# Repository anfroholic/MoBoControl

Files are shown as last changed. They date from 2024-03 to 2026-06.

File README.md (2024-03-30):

# MoBoControl Board
used to control a subset of supermicro motherboards

The info you are looking for is likely in this repo's [wiki](https://github.com/mithro/MoBoControl/wiki): look there for details

rev 1 pics 



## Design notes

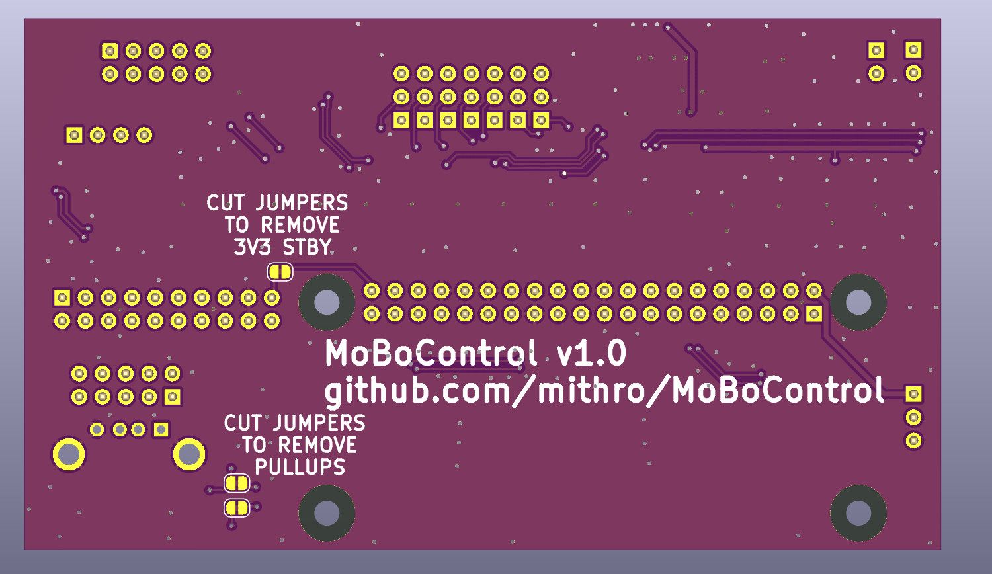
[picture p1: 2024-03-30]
cad/rev1_back.PNG

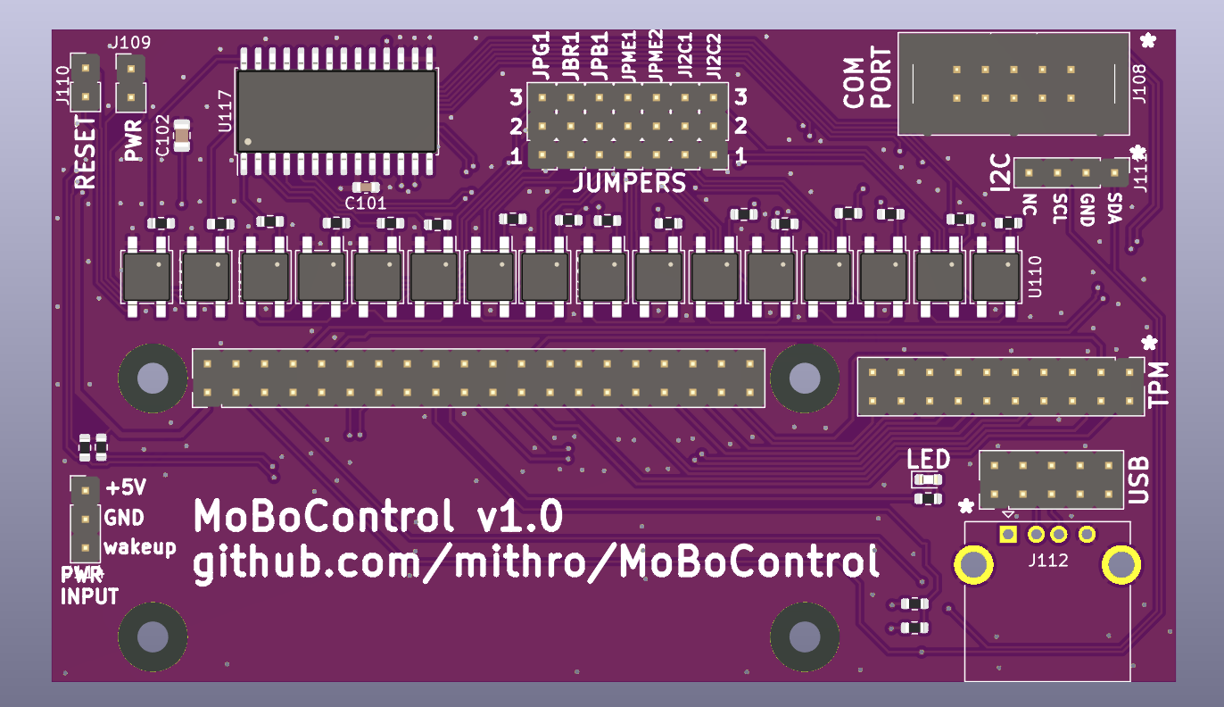
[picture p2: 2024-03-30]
cad/rev1_front.PNG

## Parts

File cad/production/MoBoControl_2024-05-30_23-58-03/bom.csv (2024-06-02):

Designator | Footprint | Quantity | Value | LCSC Part #
_4, _3, _2, | RPi_Hat_Mounting_Hole | 4
C101, C104, C105, C106, C107, C108 | 0603 | 6 | .1uF
C102, C103 | 0805 | 2 | 22uF
D115 | 0603 | 1 | led_g
H101, H102, H103, H104 | MountingHole_3.2mm_M3_DIN965 | 4 | MountingHole
J101, J102, J103, J104, J106, J107, J108 | PinHeader_1x03_P2.54mm_Vertical | 7 | Conn_01x03
J105 | PinHeader_2x04_P2.54mm_Vertical | 1 | Conn_02x04_Odd_Even
J109 | PinHeader_1x03_P2.54mm_Vertical | 1 | power_input
J110 | PinHeader_1x02_P2.54mm_Vertical | 1 | Conn_01x02
J111 | USB_A_CONNFLY_DS1095-WNR0 | 1 | USB_A
J112 | PinHeader_2x03_P2.54mm_Vertical | 1 | Conn_02x03_Odd_Even
J113 | PinHeader_1x04_P2.54mm_Vertical | 1 | Conn_01x04
J114 | PinHeader_2x05_P2.54mm_Vertical | 1 | Conn_02x05_Odd_Even
J115 | PinHeader_2x20_P2.54mm_Vertical | 1 | RPi_GPIO
J116 | PinHeader_2x10_P2.54mm_Vertical | 1 | Conn_02x10_Odd_Even
J117, J118 | PinSocket_1x15_P2.54mm_Vertical | 2 | Conn_01x15
J119 | IDC-Header_2x05_P2.54mm_Vertical | 1 | Conn_02x05_Odd_Even
JP101, JP102, JP103 | SolderJumper-2_P1.3mm_Bridged_RoundedPad1.0x1.5mm | 3 | Jumper_NC_Small
R101, R102, R103, R104, R105, R106, R107, R108, R117, R118, R119, R120, R121, R122, R123, R124, R131, R132, R133, R134, R135, R136, R137, R138, R139, R140, R141, R142, R143 | 0603 | 29 | 4.7k
SW101, SW102 | SWITCH_2x3_SMD_TACTILE_GREEN | 2 | SW_Push
U101, U102, U103, U104, U105, U106, U107, U108, U109, U110, U111, U112, U113, U114, U115, U116 | SO-4_4.4x4.3mm_P2.54mm | 16 | ASSR-1218
U117 | SOIC-28W_7.5x17.9mm_P1.27mm | 1 | MCP23017
U118 | SOIC-16_3.9x9.9mm_P1.27mm | 1 | MAX232

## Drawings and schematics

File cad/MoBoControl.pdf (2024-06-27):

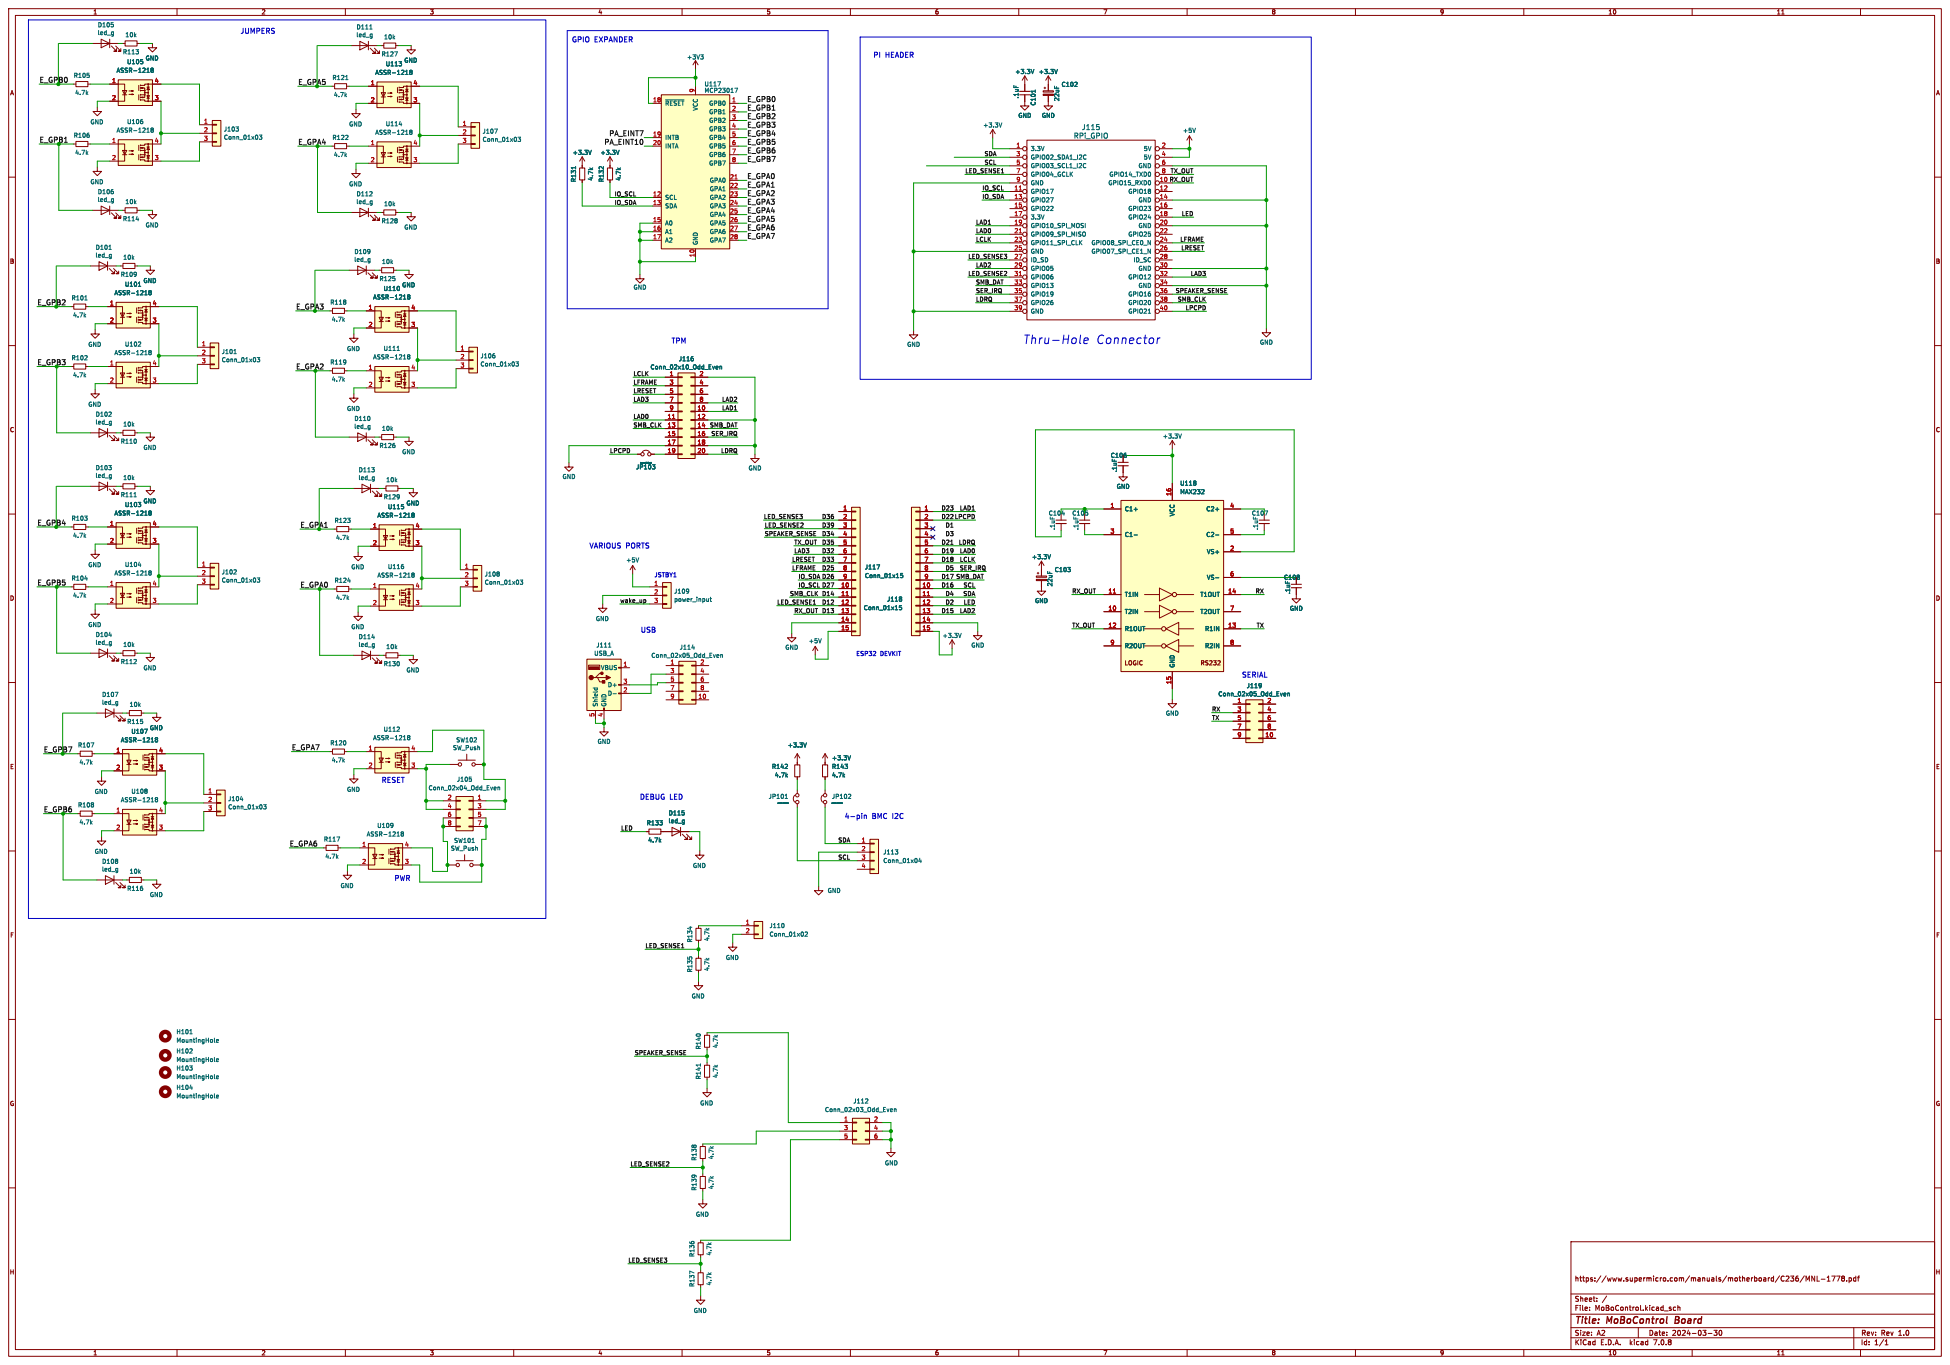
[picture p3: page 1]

GPB0 1 GND 10 SCL 12 SDA 13 A0 15 A1 16 A2 17 ~{RESET} 18

File: MoBoControl.kicad_sch Sheet: / https://www.supermicro.com/manuals/motherboard/C236/MNL-1778.pdf

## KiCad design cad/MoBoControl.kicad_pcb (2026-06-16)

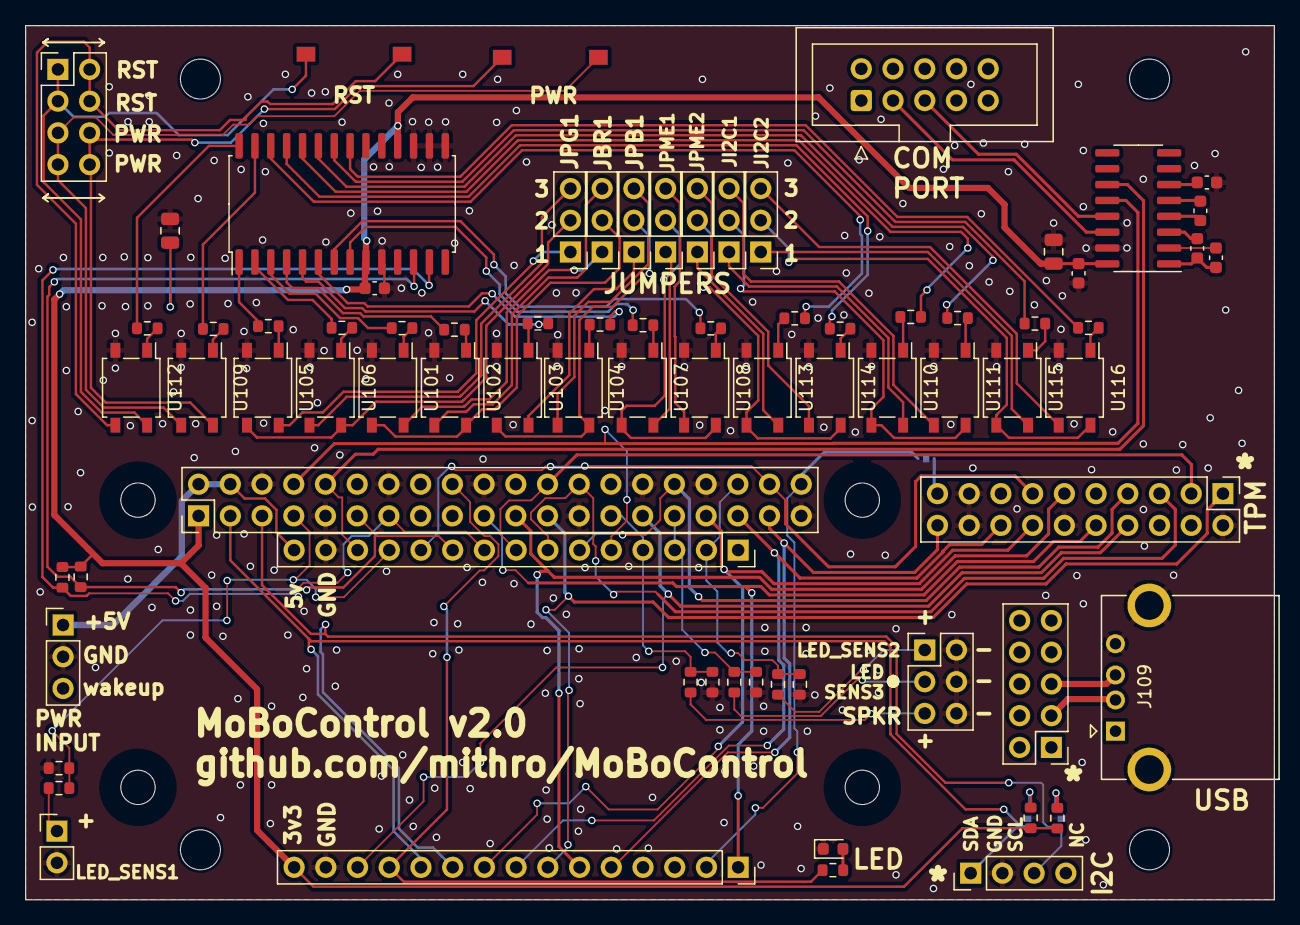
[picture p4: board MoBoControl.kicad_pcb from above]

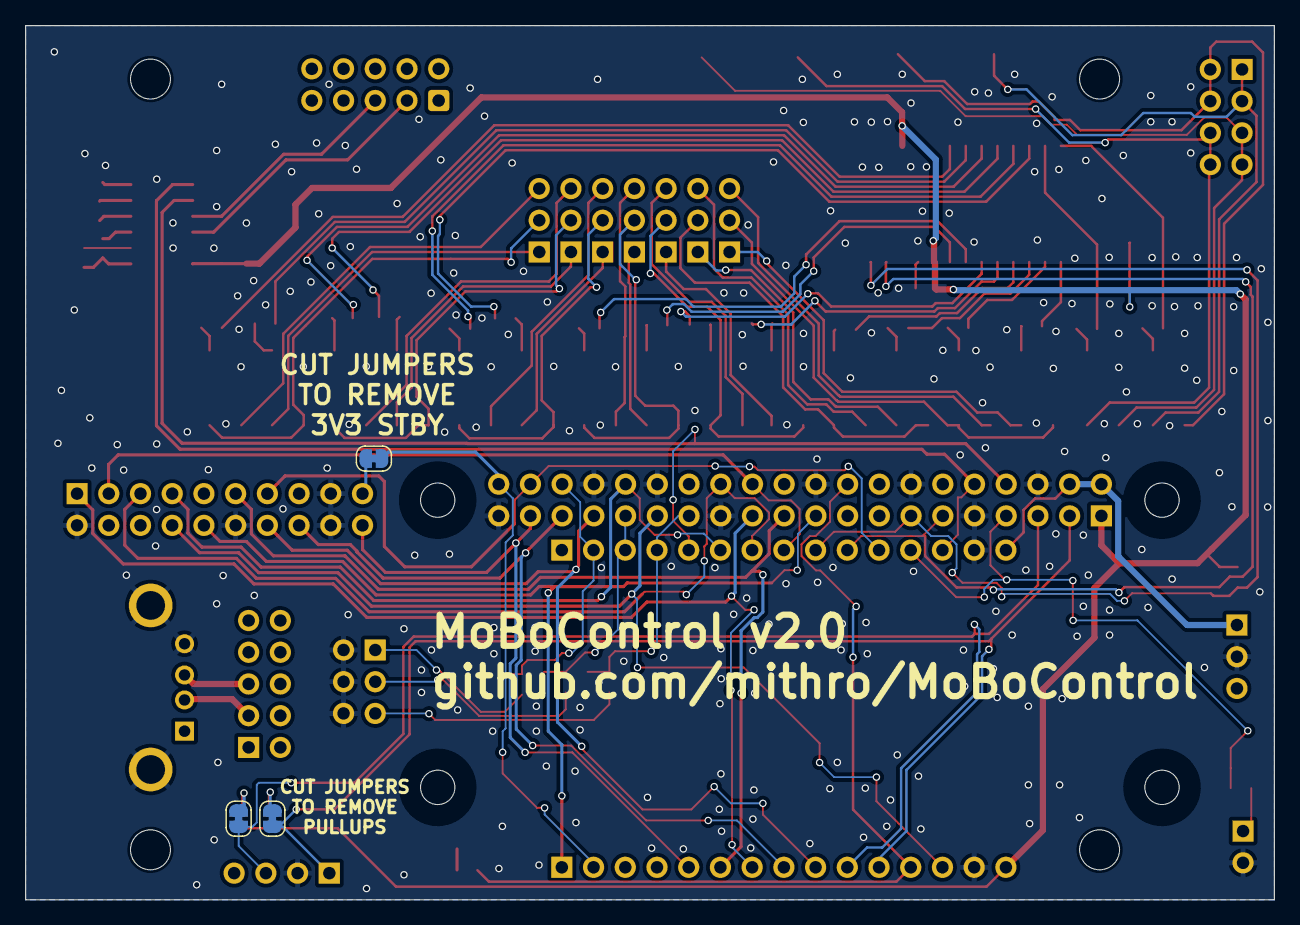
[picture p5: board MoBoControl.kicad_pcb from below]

Board: 2 copper layers, 100.0 x 70.0 mm, 84 parts (3 on the bottom side), 101 nets.

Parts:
C101, C104, C105, C106, C107, C108: .1uF; C_0603_1608Metric
C102, C103: 22uF; C_0805_2012Metric
D115: led_g; LED_0603_1608Metric
H101, H102, H103, H104: MountingHole; MountingHole_3.2mm_M3_DIN965
J101, J102, J103, J104, J106, J107, J108: Conn_01x03; PinHeader_1x03_P2.54mm_Vertical
J105: Conn_02x04_Odd_Even; PinHeader_2x04_P2.54mm_Vertical
J109: USB_A; USB_A_CONNFLY_DS1095-WNR0
J110: power_input; PinHeader_1x03_P2.54mm_Vertical
J111: Conn_02x10_Odd_Even; PinHeader_2x10_P2.54mm_Vertical
J112: Conn_02x05_Odd_Even; PinHeader_2x05_P2.54mm_Vertical
J113: Conn_01x02; PinHeader_1x02_P2.54mm_Vertical
J114, J117: Conn_01x15; PinSocket_1x15_P2.54mm_Vertical
J115: Conn_02x03_Odd_Even; PinHeader_2x03_P2.54mm_Vertical
J116: Conn_01x04; PinHeader_1x04_P2.54mm_Vertical
J118: RPi_GPIO; PinHeader_2x20_P2.54mm_Vertical
J119: Conn_02x05_Odd_Even; IDC-Header_2x05_P2.54mm_Vertical
JP101, JP102, JP103: Jumper_NC_Small; SolderJumper-2_P1.3mm_Bridged_RoundedPad1.0x1.5mm
R101, R102, R103, R104, R105, R106, R107, R108, R117, R118, R119, R120, R121, R122, R123, R124, R133, R134, R135, R136, R137, R138, R139, R140, R141, R142, R143: 220R; R_0603_1608Metric
R131, R132: 4.7k; R_0603_1608Metric
SW101, SW102: SW_Push; SWITCH_2x3_SMD_TACTILE_GREEN
U101, U102, U103, U104, U105, U106, U107, U108, U109, U110, U111, U112, U113, U114, U115, U116: ASSR-1218; SO-4_4.4x4.3mm_P2.54mm
U117: MCP23017; SOIC-28W_7.5x17.9mm_P1.27mm
U118: MAX232; SOIC-16_3.9x9.9mm_P1.27mm

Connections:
+3V3: C101.2, C102.1, C103.1, C106.1, J117.15, J118.1 (3.3V), R131.1, R132.1, R142.1, R143.1, U117.9 (VCC), U117.18 (~RESET), U118.16 (VCC)
+5V: J110.1, J114.15, J118.2 (5V), J118.4 (5V)
/D2: J117.12, J118.18 (GPIO24), R133.2
/D4: J116.1, J117.11, J118.3 (GPIO02_SDA1_I2C), JP103.1
/D5: J111.16, J117.8, J118.35 (GPIO19)
/D12: J114.12, J118.7 (GPIO04_GCLK), R134.2, R135.1
/D13: J114.13, J118.10 (GPIO15_RXD0), U118.11 (T1IN)
/D14: J111.13, J114.11, J118.38 (GPIO20)
/D15: J111.8, J117.13, J118.29 (GPIO05)
/D16: J116.3, J117.10, J118.5 (GPIO03_SCL1_I2C), JP102.1
/D17: J111.14, J117.9, J118.33 (GPIO13)
/D18: J111.1, J117.7, J118.23 (GPIO11_SPI_CLK)
/D19: J111.11, J117.6, J118.21 (GPIO09_SPI_MISO)
/D21: J111.20, J117.5, J118.37 (GPIO26)
/D22: J117.2, J118.40 (GPIO21), JP101.1
/D23: J111.10, J117.1, J118.19 (GPIO10_SPI_MOSI)
/D25: J111.3, J114.8, J118.24 (GPIO08_SPI_CE0_N)
/D26: J114.9, J118.13 (GPIO27), R131.2, U117.13 (SDA)
/D27: J114.10, J118.11 (GPIO17), R132.2, U117.12 (SCL)
/D32: J111.7, J114.6, J118.32 (GPIO12)
/D33: J111.5, J114.7, J118.26 (GPIO07_SPI_CE1_N)
/D34: J114.4, J118.36 (GPIO16), R140.2, R141.1
/D35: J114.5, J118.8 (GPIO14_TXD0), U118.12 (R1OUT)
/D36: J114.2, J118.27 (ID_SD), R136.2, R137.1
/D39: J114.3, J118.31 (GPIO06), R138.2, R139.1
/E_GPA0: R124.2, U117.21 (GPA0)
/E_GPA1: R123.2, U117.22 (GPA1)
/E_GPA2: R119.2, U117.23 (GPA2)
/E_GPA3: R118.2, U117.24 (GPA3)
/E_GPA4: R122.2, U117.25 (GPA4)
/E_GPA5: R121.2, U117.26 (GPA5)
/E_GPA6: R117.2, U117.27 (GPA6)
/E_GPA7: R120.2, U117.28 (GPA7)
/E_GPB0: R105.2, U117.1 (GPB0)
/E_GPB1: R106.2, U117.2 (GPB1)
/E_GPB2: R101.2, U117.3 (GPB2)
/E_GPB3: R102.2, U117.4 (GPB3)
/E_GPB4: R103.2, U117.5 (GPB4)
/E_GPB5: R104.2, U117.6 (GPB5)
/E_GPB6: R108.2, U117.7 (GPB6)
/E_GPB7: R107.2, U117.8 (GPB7)
/RX: J119.3, U118.14 (T1OUT)
/TX: J119.5, U118.13 (R1IN)
GND: C101.1, C102.2, C103.2, C106.2, C108.2, D115.1 (K), J109.4 (GND), J109.5 (Shield), J110.2, J111.2, J111.12, J111.17, J111.18, J113.2, J114.14, J115.2, J115.4, J115.6, J116.2, J117.14, J118.6 (GND), J118.9 (GND), J118.14 (GND), J118.20 (GND), J118.25 (GND), J118.30 (GND), J118.34 (GND), J118.39 (GND), R135.2, R137.2, R139.2, R141.2, U101.2, U102.2, U103.2, U104.2, U105.2, U106.2, U107.2, U108.2, U109.2, U110.2, U111.2, U112.2, U113.2, U114.2, U115.2, U116.2, U117.10 (GND), U117.15 (A0), U117.16 (A1), U117.17 (A2), U118.15 (GND)
unnamed: D115.2 (A), R133.1
unnamed: J101.1, U101.4
unnamed: J101.2, U101.3, U102.4
unnamed: J101.3, U102.3
unnamed: J102.1, U103.4
unnamed: J102.2, U103.3, U104.4
unnamed: J102.3, U104.3
unnamed: J103.1, U105.4
unnamed: J103.2, U105.3, U106.4
unnamed: J103.3, U106.3
unnamed: J104.1, U107.4
unnamed: J104.2, U107.3, U108.4
unnamed: J104.3, U108.3
unnamed: J105.1, J105.3, SW102.2, U112.4
unnamed: J105.2, J105.4, SW102.1, U112.3
unnamed: J105.5, J105.7, SW101.2, U109.3
unnamed: J105.6, J105.8, SW101.1, U109.4
unnamed: J106.1, U110.4
unnamed: J106.2, U110.3, U111.4
unnamed: J106.3, U111.3
unnamed: J107.1, U113.4
unnamed: J107.2, U113.3, U114.4
unnamed: J107.3, U114.3
unnamed: J108.1, U115.4
unnamed: J108.2, U115.3, U116.4
unnamed: J108.3, U116.3
unnamed: J109.3 (D+), J112.5
unnamed: J109.2 (D-), J112.3
unnamed: J111.19, JP101.2
unnamed: J113.1, R134.1
unnamed: J115.1, R140.1
unnamed: J115.3, R138.1
unnamed: J115.5, R136.1
unnamed: JP102.2, R142.2
unnamed: JP103.2, R143.2
unnamed: R101.1, U101.1
unnamed: R102.1, U102.1
unnamed: R103.1, U103.1
unnamed: R104.1, U104.1
unnamed: R105.1, U105.1
unnamed: R106.1, U106.1
unnamed: R107.1, U107.1
unnamed: R108.1, U108.1
unnamed: R117.1, U109.1
unnamed: R118.1, U110.1
unnamed: R119.1, U111.1
unnamed: R120.1, U112.1
unnamed: R121.1, U113.1
unnamed: R122.1, U114.1
unnamed: R123.1, U115.1
unnamed: R124.1, U116.1
unnamed: C104.1, C105.1, U118.1 (C1+)
unnamed: C105.2, U118.3 (C1-)
unnamed: C107.1, U118.4 (C2+)
unnamed: C107.2, U118.5 (C2-)
unnamed: C104.2, U118.2 (VS+)
unnamed: C108.1, U118.6 (VS-)

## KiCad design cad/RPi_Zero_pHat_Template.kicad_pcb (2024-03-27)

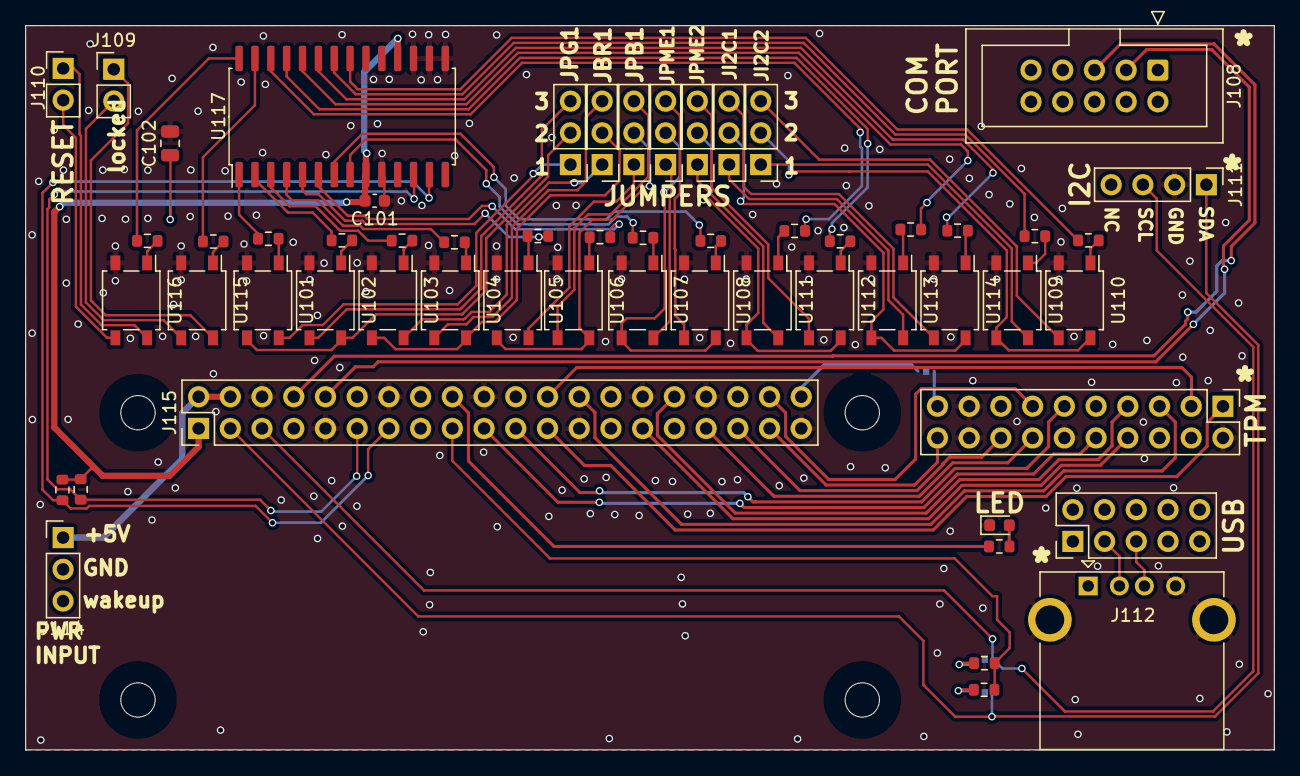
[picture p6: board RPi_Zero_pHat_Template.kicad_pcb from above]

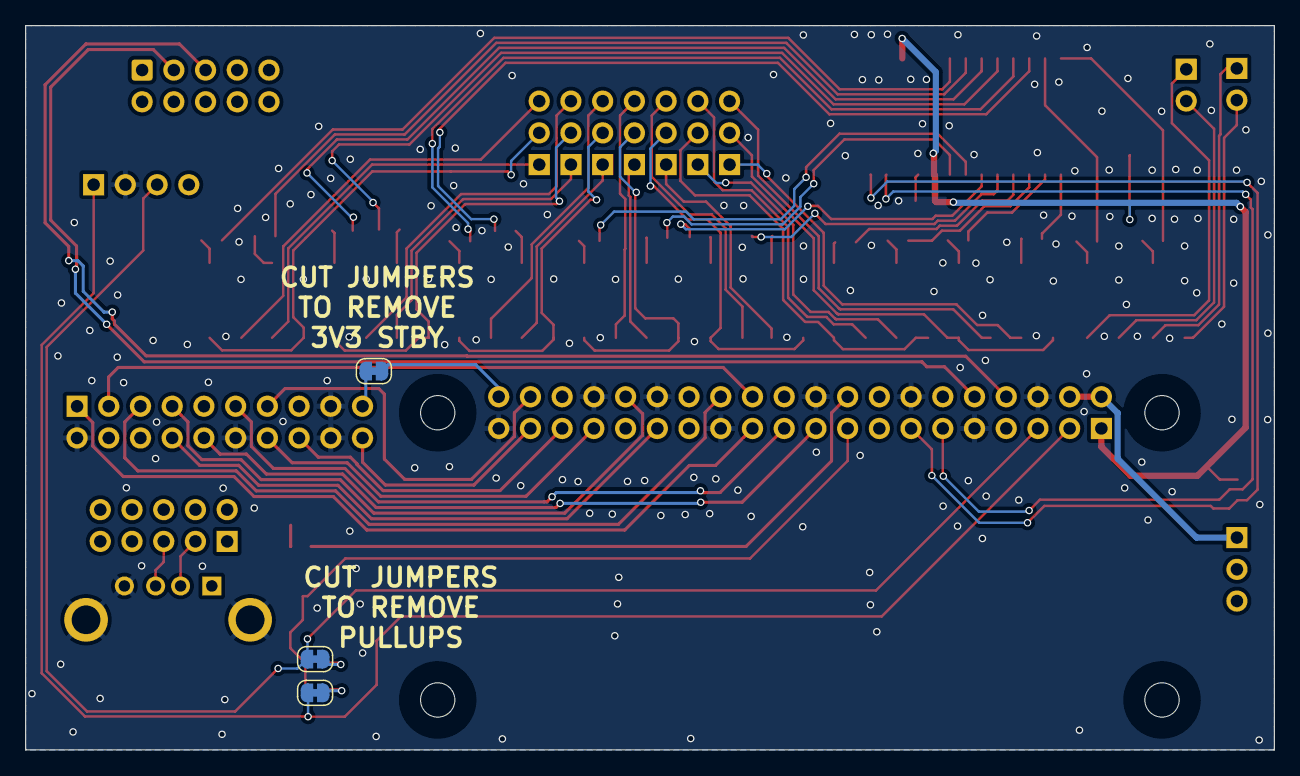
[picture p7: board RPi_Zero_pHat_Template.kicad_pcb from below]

Board: 2 copper layers, 100.0 x 58.0 mm, 60 parts (3 on the bottom side), 85 nets.

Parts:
C101: .1uF; C_0603_1608Metric
C102: 22uF; C_0805_2012Metric
D115: led_g; LED_0603_1608Metric
J101, J102, J103, J104, J105, J106, J107: Conn_01x03; PinHeader_1x03_P2.54mm_Vertical
J108: Conn_02x05_Odd_Even; IDC-Header_2x05_P2.54mm_Vertical
J109, J110: Conn_01x02; PinHeader_1x02_P2.54mm_Vertical
J111: Conn_01x04; PinHeader_1x04_P2.54mm_Vertical
J112: USB_A; USB_A_CONNFLY_DS1095-WNR0
J113: Conn_02x05_Odd_Even; PinHeader_2x05_P2.54mm_Vertical
J114: power_input; PinHeader_1x03_P2.54mm_Vertical
J115: RPi_GPIO; PinHeader_2x20_P2.54mm_Vertical
J116: Conn_02x10_Odd_Even; PinHeader_2x10_P2.54mm_Vertical
JP101, JP102, JP103: Jumper_NC_Small; SolderJumper-2_P1.3mm_Bridged_RoundedPad1.0x1.5mm
R101, R102, R103, R104, R105, R106, R107, R108, R117, R118, R119, R120, R121, R122, R129, R130, R131, R132, R133, R134, R135: 4.7k; R_0603_1608Metric
U101, U102, U103, U104, U105, U106, U107, U108, U109, U110, U111, U112, U113, U114, U115, U116: ASSR-1218; SO-4_4.4x4.3mm_P2.54mm
U117: MCP23017; SOIC-28W_7.5x17.9mm_P1.27mm

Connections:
+3V3: C101.2, C102.1, J115.1 (3.3V), J115.17 (3.3V), R131.1, R133.1, R134.1, R135.1, U117.9 (VCC), U117.18 (~RESET)
+5V: J114.1, J115.2 (5V), J115.4 (5V)
/E_GPA0: R118.2, U117.21 (GPA0)
/E_GPA1: R117.2, U117.22 (GPA1)
/E_GPA2: R122.2, U117.23 (GPA2)
/E_GPA3: R121.2, U117.24 (GPA3)
/E_GPA4: R120.2, U117.25 (GPA4)
/E_GPA5: R119.2, U117.26 (GPA5)
/E_GPA6: R129.2, U117.27 (GPA6)
/E_GPA7: R130.2, U117.28 (GPA7)
/E_GPB0: R101.2, U117.1 (GPB0)
/E_GPB1: R102.2, U117.2 (GPB1)
/E_GPB2: R103.2, U117.3 (GPB2)
/E_GPB3: R104.2, U117.4 (GPB3)
/E_GPB4: R105.2, U117.5 (GPB4)
/E_GPB5: R106.2, U117.6 (GPB5)
/E_GPB6: R108.2, U117.7 (GPB6)
/E_GPB7: R107.2, U117.8 (GPB7)
/IO_SCL: J115.11 (GPIO17), R135.2, U117.12 (SCL)
/IO_SDA: J115.13 (GPIO27), R134.2, U117.13 (SDA)
/LAD0: J115.21 (GPIO09_SPI_MISO), J116.11
/LAD1: J115.19 (GPIO10_SPI_MOSI), J116.10
/LAD2: J115.29 (GPIO05), J116.8
/LAD3: J115.32 (GPIO12), J116.7
/LCLK: J115.23 (GPIO11_SPI_CLK), J116.1
/LDRQ: J115.37 (GPIO26), J116.20
/LED: J115.18 (GPIO24), R132.2
/LFRAME: J115.24 (GPIO08_SPI_CE0_N), J116.3
/LPCPD: J115.40 (GPIO21), JP103.1
/LRESET: J115.26 (GPIO07_SPI_CE1_N), J116.5
/RX: J108.3, J115.10 (GPIO15_RXD0)
/SCL: J111.3, J115.5 (GPIO03_SCL1_I2C), JP101.1
/SDA: J111.1, J115.3 (GPIO02_SDA1_I2C), JP102.1
/SER_IRQ: J115.35 (GPIO19), J116.16
/SMB_CLK: J115.38 (GPIO20), J116.13
/SMB_DAT: J115.33 (GPIO13), J116.14
/TX: J108.5, J115.8 (GPIO14_TXD0)
GND: C101.1, C102.2, D115.1 (K), J111.2, J112.4 (GND), J112.5 (Shield), J115.6 (GND), J115.9 (GND), J115.14 (GND), J115.20 (GND), J115.25 (GND), J115.30 (GND), J115.34 (GND), J115.39 (GND), J116.2, J116.12, J116.17, J116.18, U101.2, U102.2, U103.2, U104.2, U105.2, U106.2, U107.2, U108.2, U109.2, U110.2, U111.2, U112.2, U113.2, U114.2, U115.2, U116.2, U117.10 (GND), U117.15 (A0), U117.16 (A1), U117.17 (A2)
unnamed: D115.2 (A), R132.1
unnamed: J101.1, U101.4
unnamed: J101.2, U101.3, U102.4
unnamed: J101.3, U102.3
unnamed: J102.1, U103.4
unnamed: J102.2, U103.3, U104.4
unnamed: J102.3, U104.3
unnamed: J103.1, U105.4
unnamed: J103.2, U105.3, U106.4
unnamed: J103.3, U106.3
unnamed: J104.1, U107.4
unnamed: J104.2, U107.3, U108.4
unnamed: J104.3, U108.3
unnamed: J105.1, U109.4
unnamed: J105.2, U109.3, U110.4
unnamed: J105.3, U110.3
unnamed: J106.1, U111.4
unnamed: J106.2, U111.3, U112.4
unnamed: J106.3, U112.3
unnamed: J107.1, U113.4
unnamed: J107.2, U113.3, U114.4
unnamed: J107.3, U114.3
unnamed: J109.1, U115.4
unnamed: J109.2, U115.3
unnamed: J110.1, U116.4
unnamed: J110.2, U116.3
unnamed: J112.3 (D+), J113.5
unnamed: J112.2 (D-), J113.3
unnamed: J116.19, JP103.2
unnamed: JP101.2, R131.2
unnamed: JP102.2, R133.2
unnamed: R101.1, U101.1
unnamed: R102.1, U102.1
unnamed: R103.1, U103.1
unnamed: R104.1, U104.1
unnamed: R105.1, U105.1
unnamed: R106.1, U106.1
unnamed: R107.1, U107.1
unnamed: R108.1, U108.1
unnamed: R117.1, U109.1
unnamed: R118.1, U110.1
unnamed: R119.1, U111.1
unnamed: R120.1, U112.1
unnamed: R121.1, U113.1
unnamed: R122.1, U114.1
unnamed: R129.1, U115.1
unnamed: R130.1, U116.1

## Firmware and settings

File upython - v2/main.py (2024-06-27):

from machine import Pin, SoftI2C
import utime
import mcp23017

i2c = SoftI2C(scl=Pin(27), sda=Pin(26), freq=100000)
print(i2c.scan()) # scan for devices
led = Pin(2, Pin.OUT)

mcp = mcp23017.MCP23017(i2c)
time_between_frames = 5

# hardware pins
reset_pin = 7
pwr_pin = 6
jumper_pins = {
    "JPG1": (8, 9),
    "JBR1": (10, 11),
    "JPB1": (12, 13),
    "JPME1": (15, 14),
    "JPME2": (5, 4),
    "JI2C1": (3, 2),
    "JI2C2": (1, 0),
}

def pulse_reset():
    print('pulsing reset')
    mcp[reset_pin].value(1)
    utime.sleep(5)
    mcp[reset_pin].value(0)
    print('reset pulsed')

def pulse_power():
    print('pulsing power')  
    mcp[pwr_pin].value(1)
    utime.sleep(1)
    mcp[pwr_pin].value(0)
    print('power pulsed')  

class Jumper:
    def __init__(self, mcp, pin_0, pin_1):
        self.mcp = mcp
        self.pin_0 = pin_0  # 1 -> 2
        self.pin_1 = pin_1  # 2 -> 3
        self.value = None
        self.setup()
        
    def setup(self):
        """init the device pins"""
        self.mcp.pin(self.pin_0, mode=0, value=0)
        utime.sleep_ms(time_between_frames)
        self.mcp.pin(self.pin_1, mode=0, value=0)
        utime.sleep_ms(time_between_frames)
        
    def on(self):
        """jumps jumper 2->3 """
        self.mcp[self.pin_0].value(0)
        utime.sleep_ms(time_between_frames)
        self.mcp[self.pin_1].value(1)
        self.value = 1
        utime.sleep_ms(time_between_frames)
        
    def off(self):
        """jumps jumper 1->2 """
        self.mcp[self.pin_1].value(0)
        utime.sleep_ms(time_between_frames)
        self.mcp[self.pin_0].value(1)
        self.value = 0
        utime.sleep_ms(time_between_frames)
        
    def none(self):
        """desconnects all jumpers """
        self.mcp[self.pin_1].value(0)
        utime.sleep_ms(time_between_frames)
        self.mcp[self.pin_0].value(0)
        self.value = None
        utime.sleep_ms(time_between_frames)

print('mcp23017 device')
# init the power and reset pins
mcp.pin(pwr_pin, mode=0, value=0)
utime.sleep_ms(time_between_frames)
mcp.pin(reset_pin, mode=0, value=0)
utime.sleep_ms(time_between_frames)

jumpers = {name: Jumper(mcp, pin[0], pin[1]) for name, pin in jumper_pins.items()}
print('mcp23017 initted')

def list_jumper_values():
    for k, v in jumpers.items():
        print(f"{k}: {v.value}")


def beep():
    print('posted')
    
# spkr = Pin(34, Pin.IN)
# spkr.irq(trigger=Pin.IRQ_RISING, handler=beep)

# from machine import ADC
# spkr = ADC(Pin(34))
# spkr.atten(ADC.ATTN_11DB)
# threshold = 5000

# from machine import UART
# uart = UART(1, baudrate=9600, tx=13, rx=35)
# print(f'message: {uart.read()}' if uart.any() else '0')


# while True:
#     if spkr.read_u16() > threshold:
#         print('posted')
#         utime.sleep(1)
    
#     utime.sleep(.001)

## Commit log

2024-03-15 board template added
    [RPi_Zero_pHat_Template.kicad_pcb, RPi_Zero_pHat_Template.sch]
2024-03-15 update schematic
    [RPi_Zero_pHat_Template.kicad_sch]
2024-03-17 some headers added
    [RPi_Zero_pHat_Template.kicad_pcb, RPi_Zero_pHat_Template.kicad_sch]
2024-03-23 check in before tpm
    [RPi_Zero_pHat_Template.kicad_pcb, RPi_Zero_pHat_Template.kicad_sch]
2024-03-25 rev 0.1
    [RPi_Zero_pHat_Template.kicad_pcb]
2024-03-25 move spi pins
    [RPi_Zero_pHat_Template.kicad_pcb, RPi_Zero_pHat_Template.kicad_sch]
2024-03-27 add led
    [RPi_Zero_pHat_Template.kicad_pcb]
2024-03-30 rev1 cleanup
    [MoBoControl.kicad_pcb, MoBoControl.kicad_sch, RPi_Zero_pHat_Template.sch]
2024-05-16 add upython test code with ESP32
2024-06-02 Mobo V2 sent off for production
    [MoBoControl.kicad_pcb, MoBoControl.kicad_sch, bom.csv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]
2024-06-13 modify pin #s
2024-06-27 make pdf of schematic
    [MoBoControl.kicad_pcb]
